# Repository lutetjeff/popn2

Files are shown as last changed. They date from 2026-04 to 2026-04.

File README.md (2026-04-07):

# popn2 (lutet)

version 2 of my personal pop'n music controller! we don't talk about version 1.

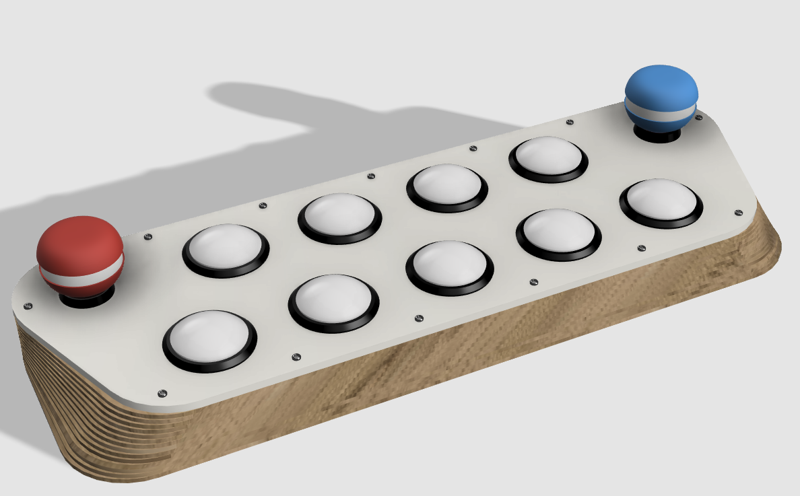
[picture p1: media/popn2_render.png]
Render of the Controller

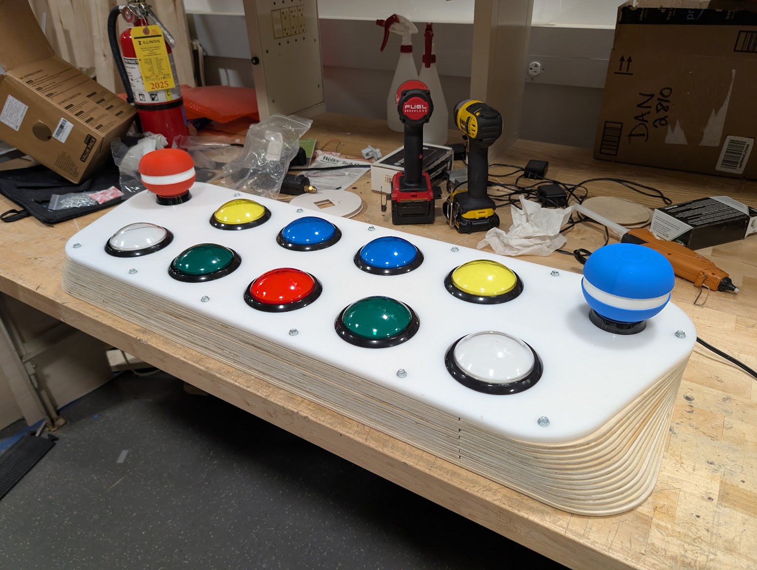
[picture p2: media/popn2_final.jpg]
Final Product

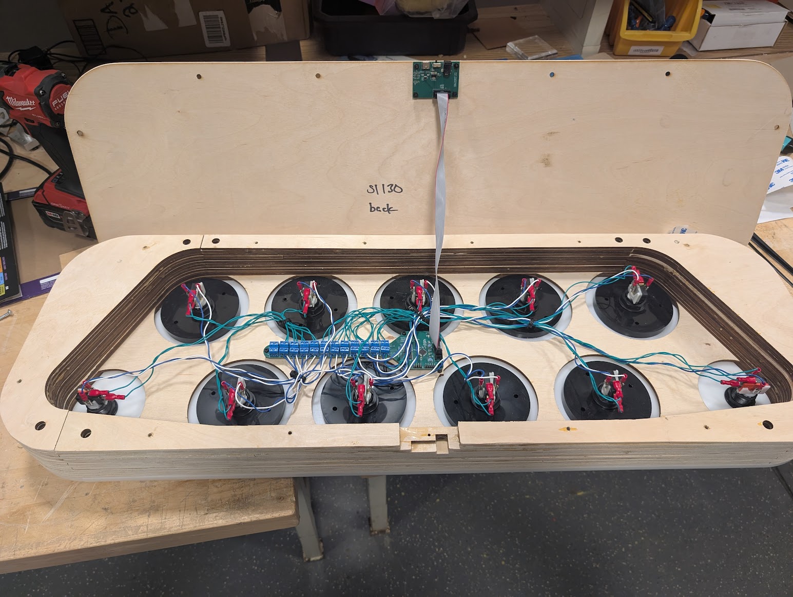
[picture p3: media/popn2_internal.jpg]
Internal Shot


here is me clearing my first 44 on this controller: [video link](https://github.com/user-attachments/assets/4b452afc-de7f-416d-95ad-3e25626bb59a)

## Repository Hierarchy

- **`daughterboard/`**: KiCAD PCB files for the USB and power daughterboard.
- **`firmware/`**: Source code for the mainboard's firmware.
- **`mainboard/`**: KiCAD PCB files for the STM32F072 mainboard.
- **`media/`**: Images, renders, and video showcases of the controller.
- **`production/`**: Vector files for laser-cutting the physical enclosure layers.
- **`popn2.f3z`**: Fusion 360 source file for the mechanical design.

## Mechanical Design

The physical enclosure of the controller is built using a stacked layer design. The stackup consists of:
- **13 layers of birch plywood** (Layers 1 through 13). The nominal thickness is 1/4", but the actual real-world thickness is about **5.2mm** per layer.
- **1 layer of acetal/POM** measuring **3/8" (9.5mm)** thick for the top layer.

### Buttons & Hardware
- **Gameplay Buttons:** We use 100mm Samducksa buttons from ISTMALL for the 9 main gameplay buttons. We highly recommend getting the aftermarket 100g Samducksa springs from ISTMALL rather than using the stock springs.
- **Side Buttons (Pop-kuns):** The side buttons are these 60mm OEM round buttons: [Amazon Link](https://www.amazon.com/dp/B09CYMDZCR)

## Mainboard

The mainboard is powered by an **STM32F072** microcontroller, and also functions as a generic 12-input 12-output arcade game controller. It uses individual pins for each button and darlington arrays to drive 12V LEDs.

## Daughterboard

The daughterboard handles the external inputs for the controller. The KiCAD PCB files define a board that takes **12V and USB in** and passes them along to the mainboard via a **10-pin (2x5) ribbon cable**.

## Firmware

The firmware for the STM32F072 on the mainboard is included in this repository.
For more details, please see the [firmware README](firmware/README.md).

## Production

The `production/` folder contains the production files for laser cutting each individual layer. 
The naming convention for these files is `sl[layer][part]`, where `[part]` is at most one digit.
There are also combined production files in `production/combined/` - beware that one of the pieces is missing and I don't remember which one. 

## Special Thanks

- **Illini Rhythm Syndicate** ([link](https://uiucirs.com))
- **ECE OpenLab at UIUC** ([link](https://openlab.ece.illinois.edu/))

## As Seen At

- Rumble In The Prairie 15 (RIP 15) - [link](https://www.start.gg/tournament/rumble-in-the-prairie-15/details)
- IRSCTF 2026 - [link](https://ctf.uiucirs.com/)
- This controller is so awesome [they made a whole song about it](https://www.youtube.com/watch?v=c7E-tgmFuzw)

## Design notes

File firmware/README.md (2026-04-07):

# popn2_firmware

STM32F072CBT6 firmware for a 12-input, 12-output rhythm game controller.

## Hardware

- **MCU**: STM32F072CBT6 (ARM Cortex-M0, 48MHz)
- **Inputs**: 12 buttons (B0-B11), active-low with pull-ups
- **Outputs**: 12 LEDs (L0-L11)
- **USB**: 1kHz HID + CDC

## Features

- **NKRO Keyboard HID**: All 12 buttons report simultaneously as HID keyboard keys
- **CDC Serial Config**: Virtual COM port for runtime configuration
- **Flash Persistence**: All settings saved to internal flash
- **DFU Bootloader**: Jump to ST's built-in ROM bootloader for firmware updates

## Building & Flashing

Requires [STM32-for-VSCode](https://marketplace.visualstudio.com/items?item=bmd.stm32-for-vscode) extension.

```bash
# Build
Ctrl+Shift+B > Build STM

# Flash
Ctrl+Shift+B > Flash STM
```

## Configuration Commands (CDC)

Connect to the Virtual COM port at 115200 baud.

| Command | Description |
|---|---|
| `e 0/1` | Disable/Enable global LEDs |
| `t <ms>` | Set global debounce time (ms) |
| `k <btn> <hex>` | Set keycode for button (e.g. `k 0 0x04`) |
| `m <btn> <mode>` | Set LED mode: 0=Direct, 1=COM Controlled |
| `d <btn> 0/1` | Set COM state for button LED control |
| `r <btn>` | Read current button state |
| `S` | Save current config to flash |
| `R` | Reset to defaults and save |
| `Z` | Reboot into DFU bootloader |

## Python Configurator

Run `configurator.py` for a graphical interface to configure all settings and monitor button states in real-time.

```bash
python configurator.py
```

## Pin Mapping

| Button | Pin | LED | Pin |
|---|-----|-----|-----|
| B0 | PA0 | L0 | PB12 |
| B1 | PA1 | L1 | PB13 |
| B2 | PA2 | L2 | PB14 |
| B3 | PA3 | L3 | PB15 |
| B4 | PA4 | L4 | PA8 |
| B5 | PA5 | L5 | PA9 |
| B6 | PA6 | L6 | PA10 |
| B7 | PA7 | L7 | PA15 |
| B8 | PB0 | L8 | PB3 |
| B9 | PB1 | L9 | PB4 |
| B10 | PB2 | L10 | PB5 |
| B11 | PB10 | L11 | PB6 |

## Default Keymap

B0-B9 map to HID keys `0`-`9`, B10 to `-`, B11 to `=`.

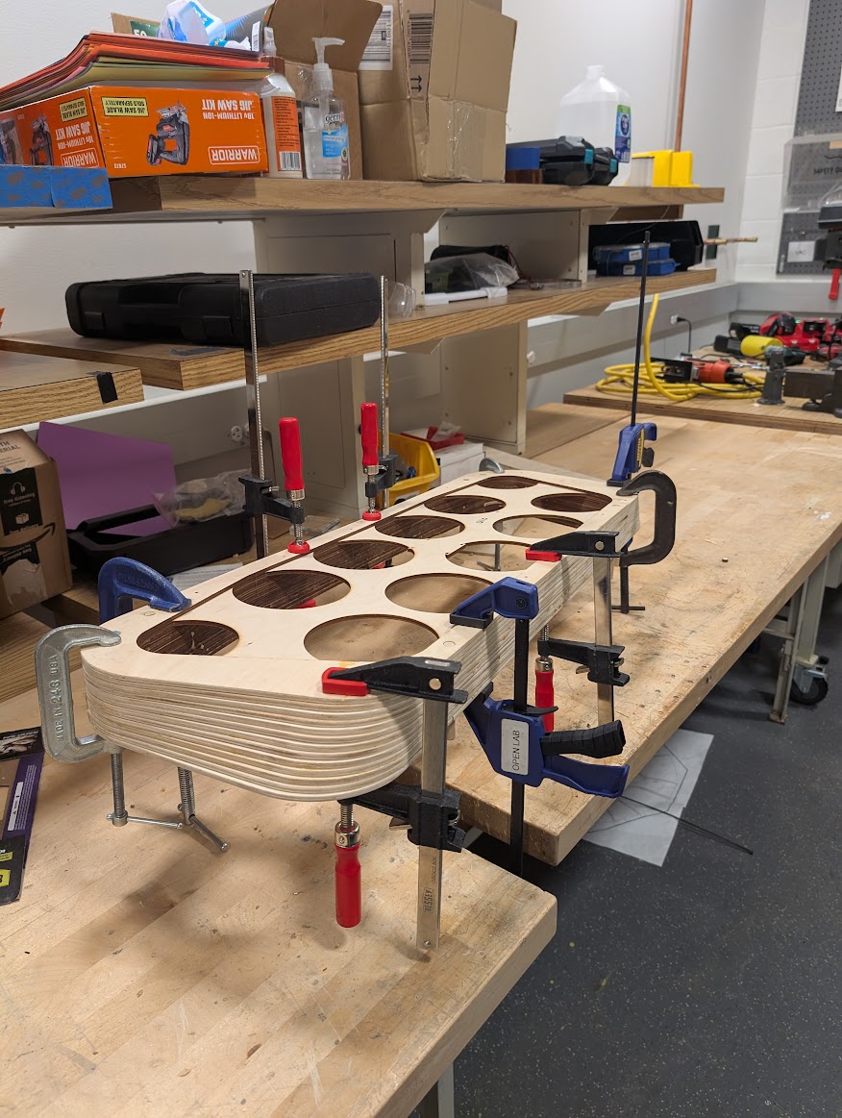
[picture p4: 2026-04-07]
media/popn2_wip.jpg

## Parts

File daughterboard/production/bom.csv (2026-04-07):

Designator | Footprint | Quantity | Value | LCSC Part #
C1 | 0805 | 1 | 1uF
C2 | 0805 | 1 | 2.2uF
D+ | TestPoint_Pad_1.5x1.5mm | 1 | D+
D- | TestPoint_Pad_1.5x1.5mm | 1 | D-
J1 | BarrelJack_Horizontal | 1 | Barrel_Jack_MountingPin
J2 | USB_C_Receptacle_HRO_TYPE-C-31-M-12 | 1 | USB_C_Receptacle_USB2.0_16P
J3 | PinHeader_2x03_P2.54mm_Vertical | 1 | PWR
J4 | PinHeader_1x02_P2.54mm_Vertical | 1 | DATA
J5 | IDC-Header_2x05_P2.54mm_Vertical | 1 | ribbon
R1, R2 | 0805 | 2 | 5.1k
SW1 | SW_Slide_SPDT_Angled_CK_OS102011MA1Q | 1 | SW_SPDT
U1 | SOT-223-3_TabPin2 | 1 | TLV76133DCY
U2 | SOT-23-6 | 1 | USBLC6-2SC6

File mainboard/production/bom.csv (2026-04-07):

Designator | Footprint | Quantity | Value | LCSC Part #
C1, C2, C3, C4 | 0805 | 4 | 0.1uF
C5 | 0805 | 1 | 1uF
D1, D2, D3, D4, D5 | 0805 | 5 | LED
J1 | IDC-Header_2x05_P2.54mm_Vertical | 1 | ribbon
J10, J11, J12, J13, J14, J15, J16, J17, J18, J19, J20, J21, J22, J23, J24, J25, J26, J3, J4, J5, J6, J7, J8, J9 | TerminalBlock_MaiXu_MX126-5.0-02P_1x02_P5.00mm | 24 | Conn_01x02
J2 | PinSocket_1x05_P2.54mm_Vertical | 1 | Conn_01x05
J27 | PinHeader_1x04_P2.54mm_Vertical | 1 | Conn_01x04
J28 | PinHeader_1x03_P2.54mm_Vertical | 1 | Conn_01x03
R1, R19, R2 | 0805 | 3 | 10k
R10, R11, R12, R13, R14, R15, R16, R5, R6, R7, R8, R9 | 0805 | 12 | 0
R17, R3, R4 | 0805 | 3 | 2.2k
R18 | 0805 | 1 | 4.7k
SW1, SW2 | SW_SPST_PTS810 | 2 | SW_Push
U1 | LQFP-48_7x7mm_P0.5mm | 1 | STM32F072C8Tx
U2, U3 | SOIC-16_3.9x9.9mm_P1.27mm | 2 | ULN2003A

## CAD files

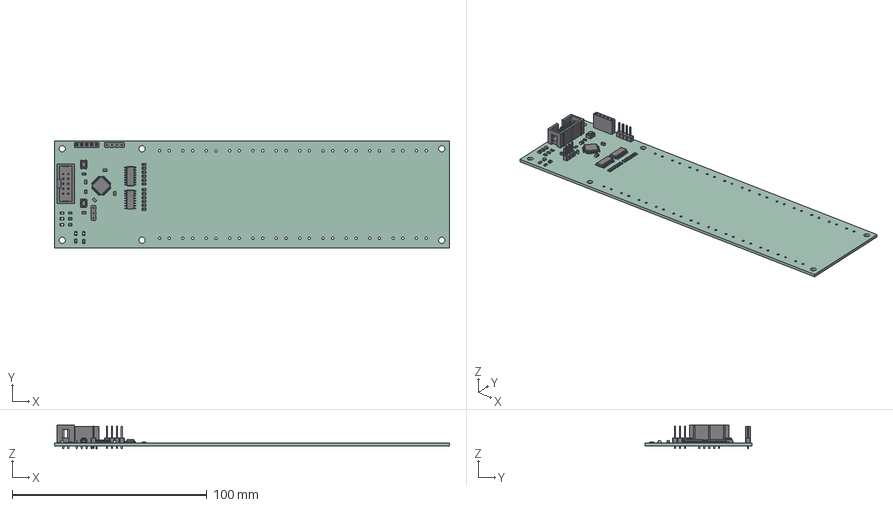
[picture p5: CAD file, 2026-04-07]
mainboard/mainboard_noss.step
203.0 x 55.0 x 12.2 mm
R_0805_2012Metric x 19
PinHeader_1x03_P2.54mm_Vertical
SOIC-16_3.9x9.9mm_P1.27mm x 2
C_0805_2012Metric x 5
SW_SPST_PTS810 x 2
LED_0805_2012Metric x 5
PinSocket_1x05_P2.54mm_Vertical
PinHeader_1x04_P2.54mm_Vertical
IDC-Header_2x05_P2.54mm_Vertical
LQFP-48_7x7mm_P0.5mm
mainboard_PCB

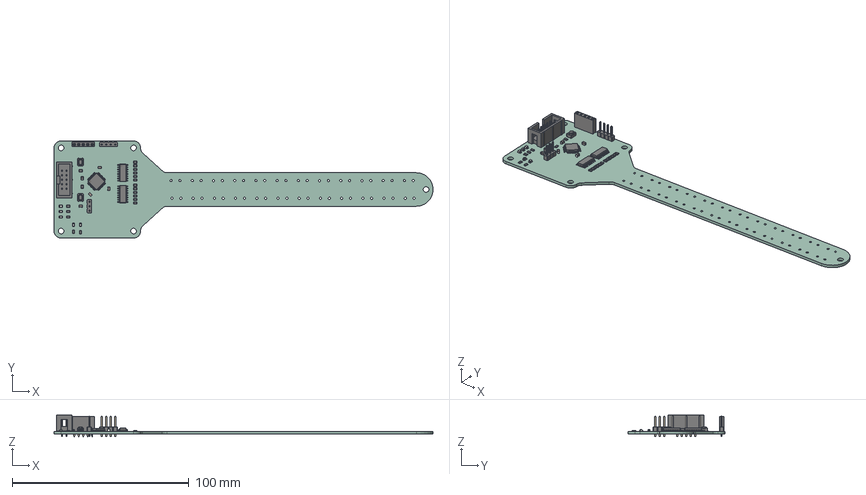
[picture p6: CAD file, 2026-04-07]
mainboard/mainboard_2.step
214.4 x 55.0 x 12.2 mm
R_0805_2012Metric x 19
PinHeader_1x03_P2.54mm_Vertical
SOIC-16_3.9x9.9mm_P1.27mm x 2
C_0805_2012Metric x 5
SW_SPST_PTS810 x 2
LED_0805_2012Metric x 5
PinSocket_1x05_P2.54mm_Vertical
PinHeader_1x04_P2.54mm_Vertical
IDC-Header_2x05_P2.54mm_Vertical
LQFP-48_7x7mm_P0.5mm
mainboard_PCB

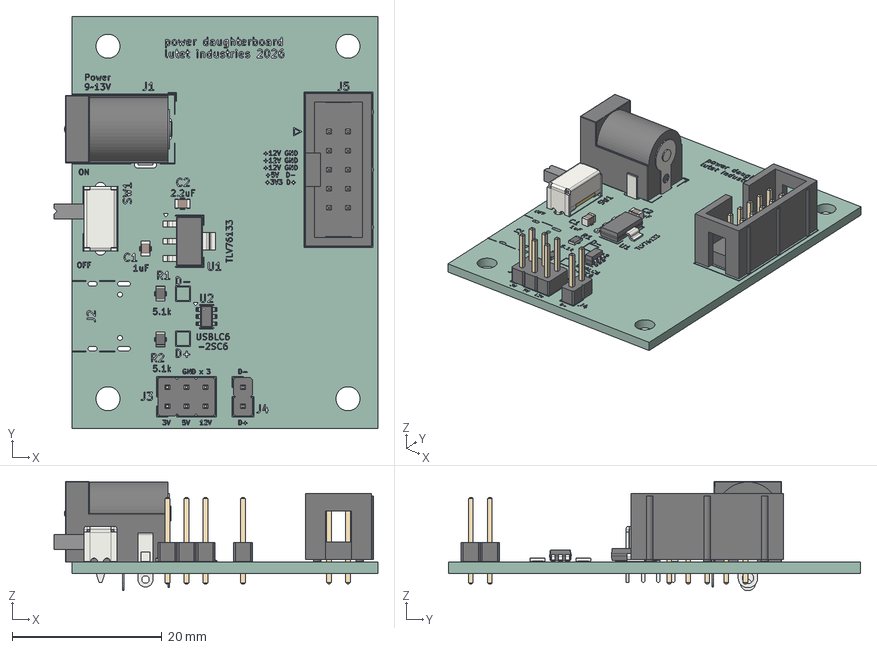
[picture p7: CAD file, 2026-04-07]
daughterboard/daughterboard.step
43.2 x 55.0 x 14.6 mm
SOT-223
C_0805_2012Metric x 2
SOT-23-6
IDC-Header_2x05_P2.54mm_Vertical
BarrelJack_Horizontal
R_0805_2012Metric x 2
PinHeader_2x03_P2.54mm_Vertical
PinHeader_1x02_P2.54mm_Vertical
SW_Slide_SPDT_Angled_CK_OS102011MA1Q
daughterboard_silkscreen x 2
daughterboard_PCB

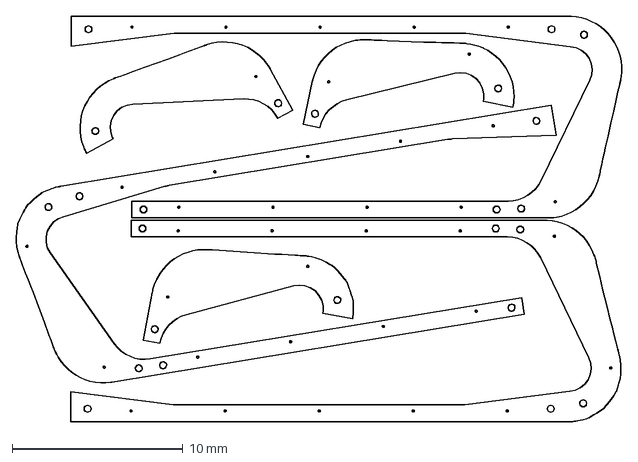
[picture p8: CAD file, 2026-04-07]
production/combined/sl30_41_50_60_71_80.dxf
35.5 x 23.8 mm

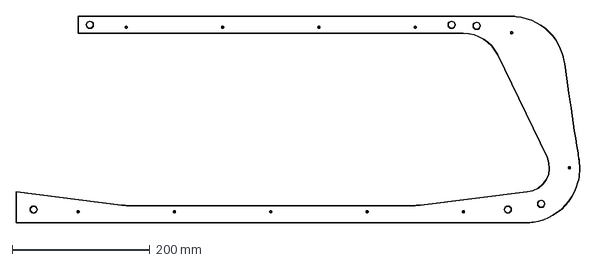
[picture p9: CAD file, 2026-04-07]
production/sl70.dxf
819.2 x 300.0 mm

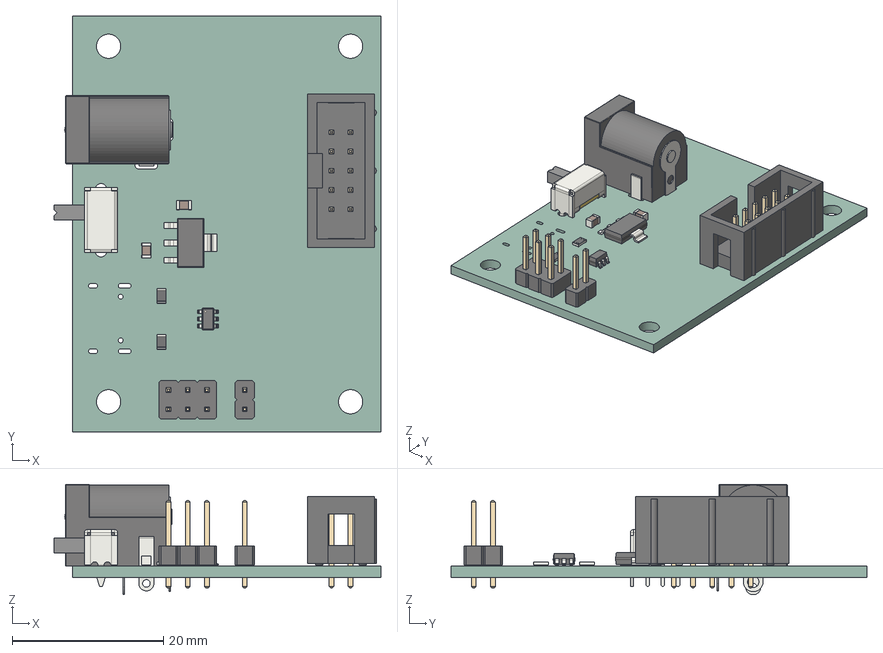
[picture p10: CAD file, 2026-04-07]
daughterboard/daughterboard_noss.step
43.2 x 55.0 x 14.6 mm
SOT-223
C_0805_2012Metric x 2
SOT-23-6
IDC-Header_2x05_P2.54mm_Vertical
BarrelJack_Horizontal
R_0805_2012Metric x 2
PinHeader_2x03_P2.54mm_Vertical
PinHeader_1x02_P2.54mm_Vertical
SW_Slide_SPDT_Angled_CK_OS102011MA1Q
daughterboard_PCB

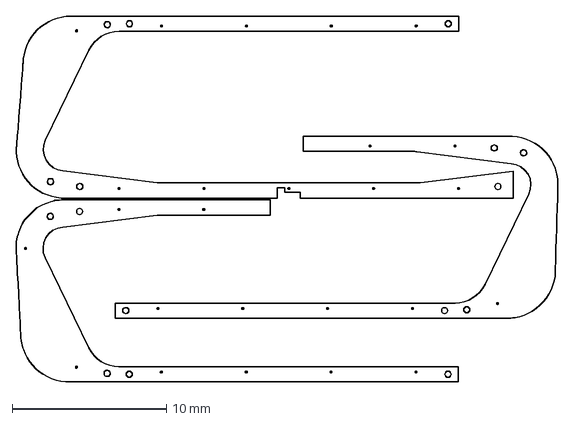
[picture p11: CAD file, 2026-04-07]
production/combined/sl_101_110_122.dxf
35.2 x 23.7 mm

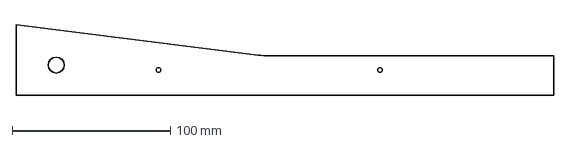
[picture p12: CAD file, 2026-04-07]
production/sl112.dxf
340.0 x 44.8 mm

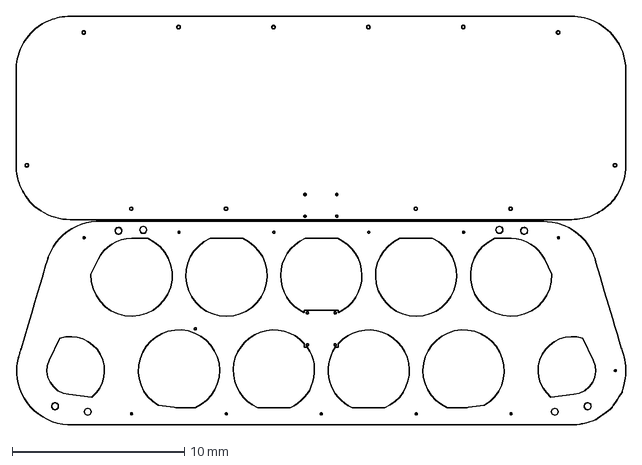
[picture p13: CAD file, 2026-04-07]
production/combined/sl10_130.dxf
35.4 x 23.7 mm

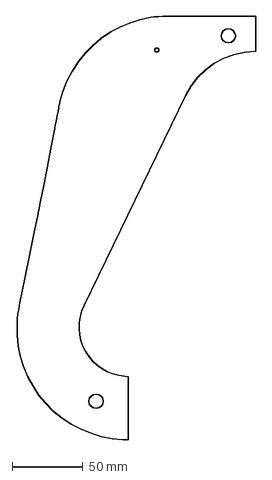
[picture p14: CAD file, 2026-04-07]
production/sl51.dxf
169.4 x 300.0 mm

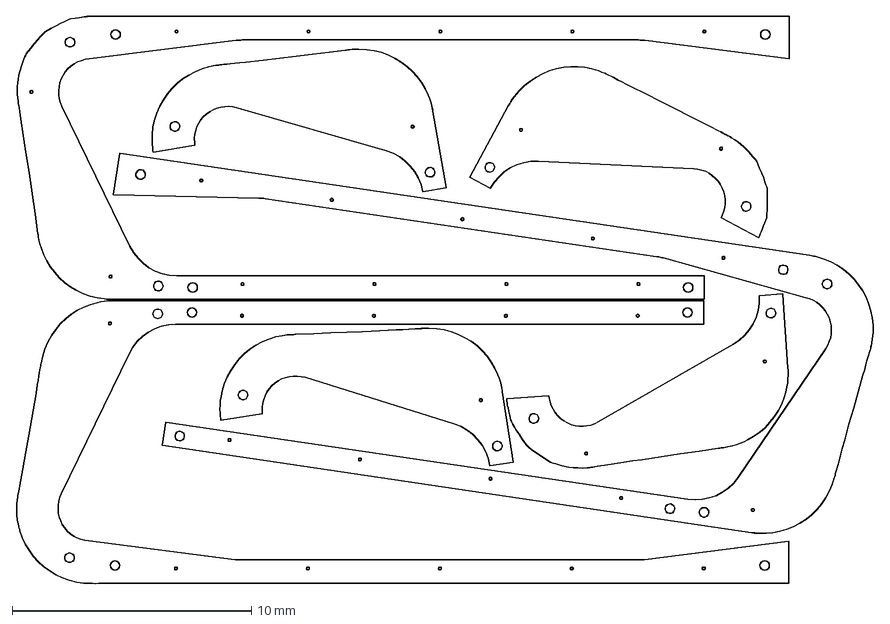
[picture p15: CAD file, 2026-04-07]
production/combined/sl61_70_81_90_91_100_111_120.dxf
35.8 x 23.7 mm

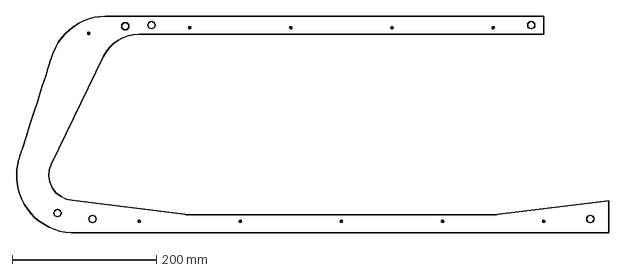
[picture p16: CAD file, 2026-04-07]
production/sl01.dxf
820.0 x 300.0 mm

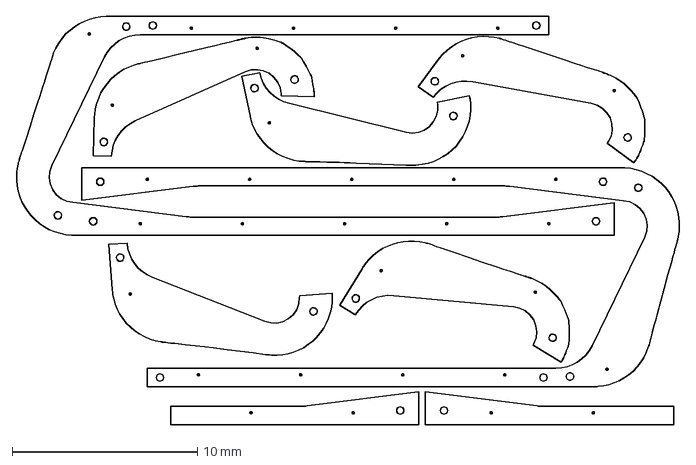
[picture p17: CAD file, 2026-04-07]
production/combined/sl00_01_20_21_31_40_51_112_121.dxf
35.8 x 22.0 mm

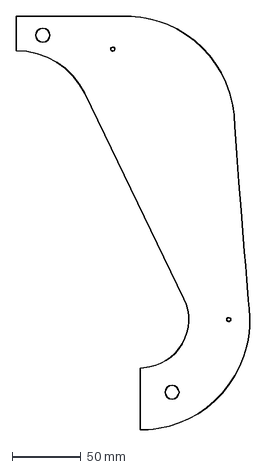
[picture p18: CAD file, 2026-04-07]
production/sl100.dxf
169.3 x 300.0 mm

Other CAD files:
production/sl120.dxf
production/sl80.dxf
production/top.dxf
production/sl122.dxf
production/foam.dxf
production/sl00.dxf
production/sl10.dxf
production/sl101.dxf
production/sl110.dxf
production/sl111.dxf
production/sl121.dxf
production/sl130.dxf
production/sl20.dxf
production/sl21.dxf
production/sl30.dxf
production/sl31.dxf
production/sl40.dxf
production/sl41.dxf
production/sl50.dxf
production/sl60.dxf
production/sl61.dxf
production/sl71.dxf
production/sl81.dxf
production/sl90.dxf
production/sl91.dxf

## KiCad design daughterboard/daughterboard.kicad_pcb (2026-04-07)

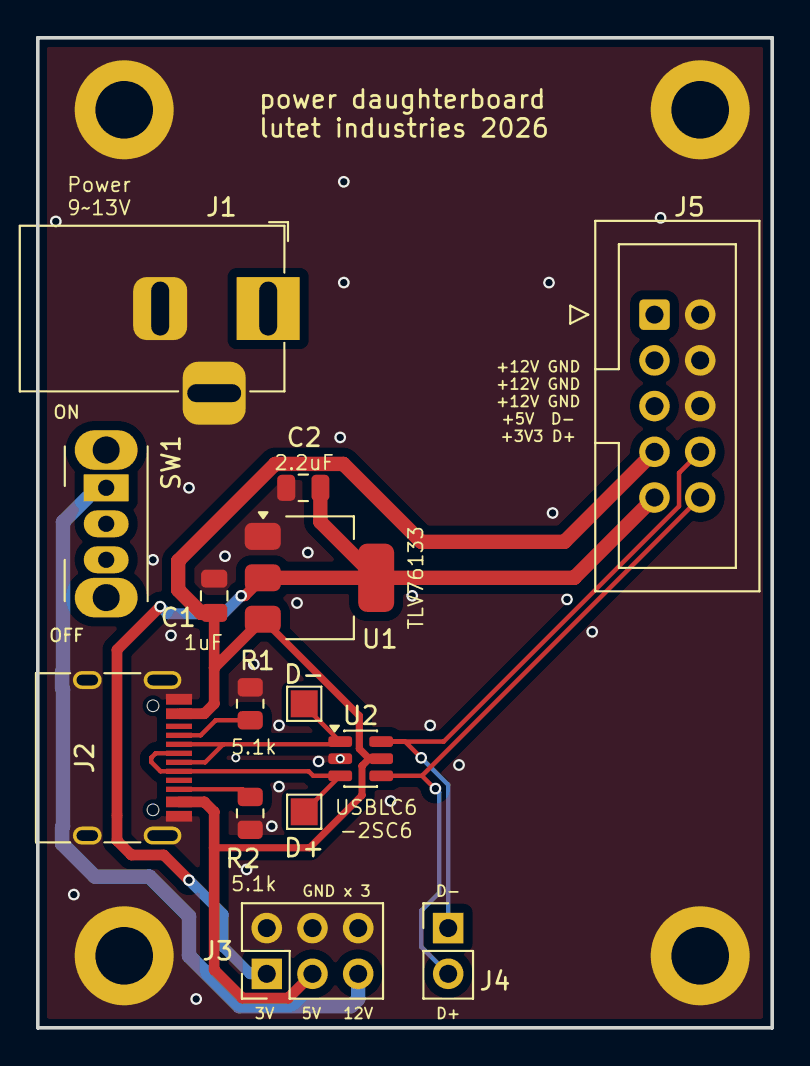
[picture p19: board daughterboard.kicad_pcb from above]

Board: 2 copper layers, 40.8 x 55.0 mm, 18 parts (0 on the bottom side), 11 nets.

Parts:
C1: 1uF; C_0805_2012Metric
C2: 2.2uF; C_0805_2012Metric
D+: D+; TestPoint_Pad_1.5x1.5mm
D-: D-; TestPoint_Pad_1.5x1.5mm
H1, H2, H3, H4: MountingHole_Pad; MountingHole_3.2mm_M3_ISO14580_Pad
J1: Barrel_Jack_MountingPin; BarrelJack_Horizontal
J2: USB_C_Receptacle_USB2.0_16P; USB_C_Receptacle_HRO_TYPE-C-31-M-12
J3: PWR; PinHeader_2x03_P2.54mm_Vertical
J4: DATA; PinHeader_1x02_P2.54mm_Vertical
J5: ribbon; IDC-Header_2x05_P2.54mm_Vertical
R1, R2: 5.1k; R_0805_2012Metric
SW1: SW_SPDT; SW_Slide_SPDT_Angled_CK_OS102011MA1Q
U1: TLV76133DCY; SOT-223-3_TabPin2
U2: USBLC6-2SC6; SOT-23-6

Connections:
+3V3: C2.1, J3.1, J5.9, U1.2 (VO)
+5V: C1.1, J2.A4 (VBUS), J2.A9 (VBUS), J2.B4 (VBUS), J2.B9 (VBUS), J3.3, J5.7, U1.3 (VI), U2.5 (VBUS)
+12V: J3.5, J5.1, J5.3, J5.5, SW1.1 (A)
D+: J4.2, J5.10, U2.4 (I/O2)
D-: J4.1, J5.8, U2.6 (I/O1)
GND: C1.2, C2.2, H1.1, H2.1, H3.1, H4.1, J1.2, J1.3 (MountPin), J2.A1 (GND), J2.A12 (GND), J2.B1 (GND), J2.B12 (GND), J2.S1 (SHIELD), J3.2, J3.4, J3.6, J5.2, J5.4, J5.6, R1.2, R2.2, U1.1 (GND), U2.2 (GND)
unnamed: J2.A5 (CC1), R1.1
unnamed: J2.B5 (CC2), R2.1
unnamed: D+.1, J2.A6 (D+), J2.B6 (D+), U2.3 (I/O2)
unnamed: D-.1, J2.A7 (D-), J2.B7 (D-), U2.1 (I/O1)
unnamed: J1.1, SW1.2 (B)

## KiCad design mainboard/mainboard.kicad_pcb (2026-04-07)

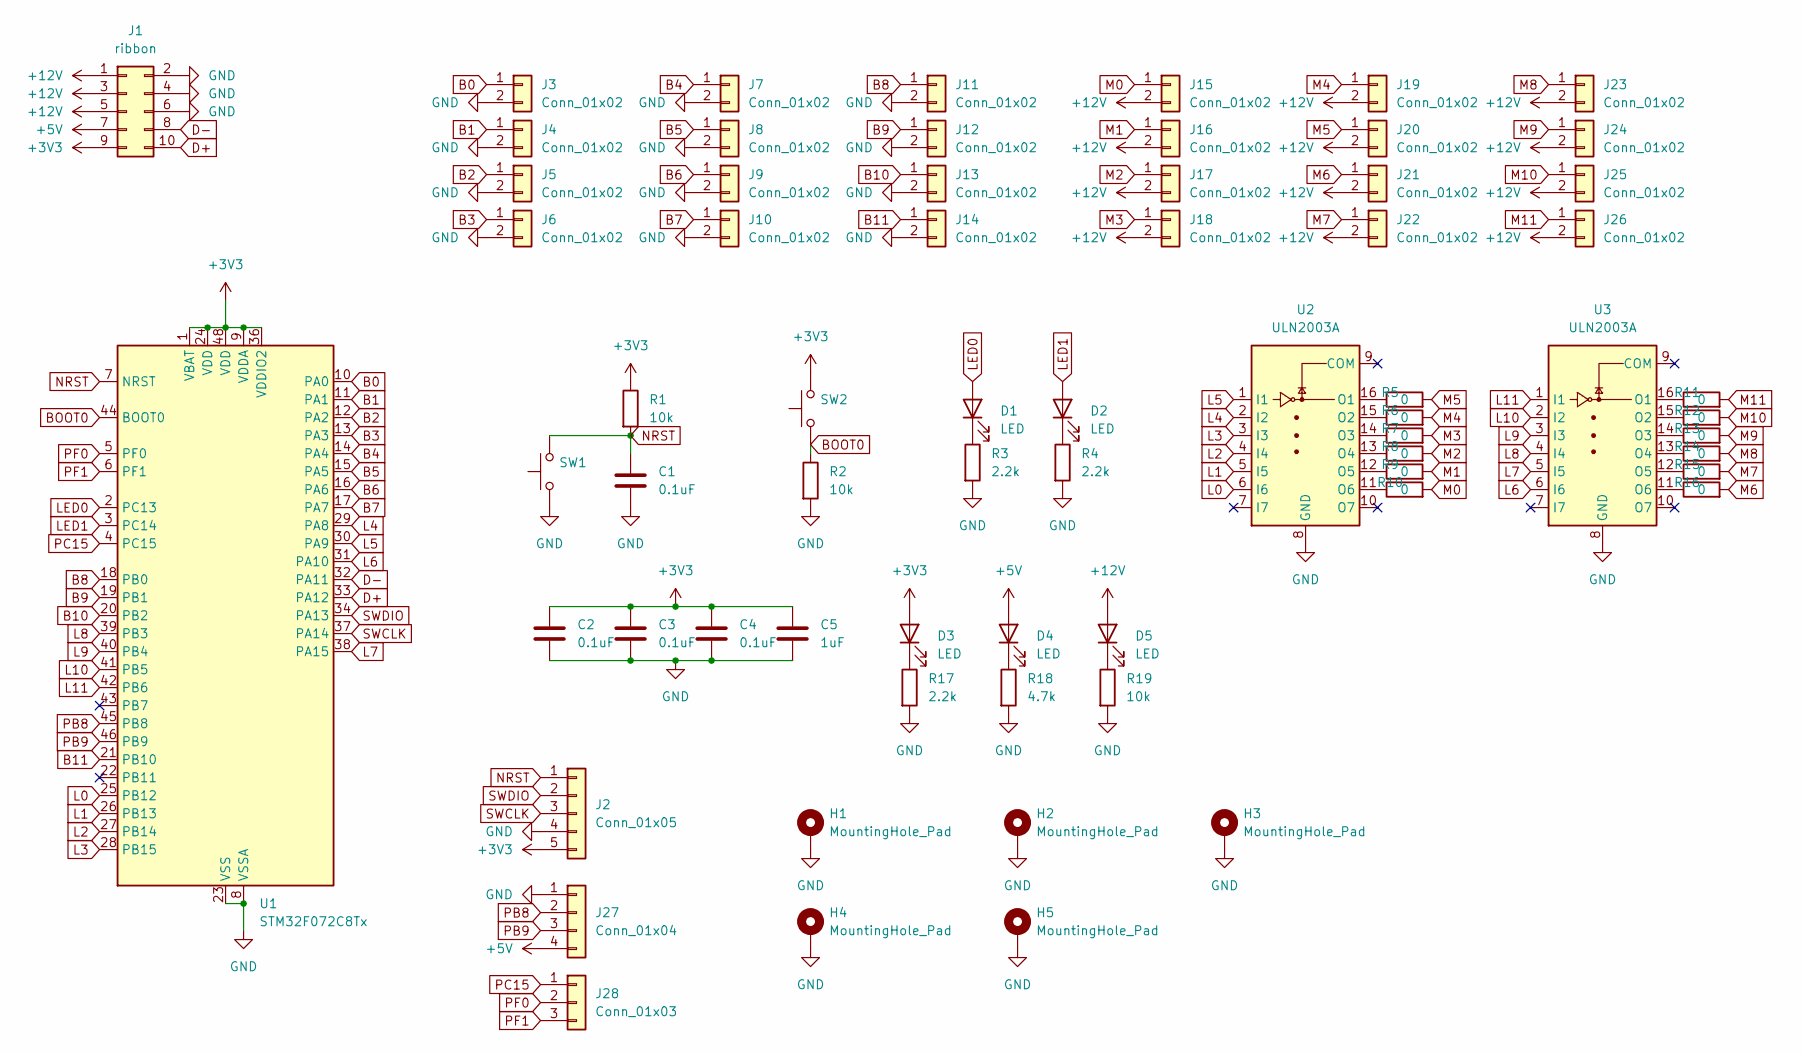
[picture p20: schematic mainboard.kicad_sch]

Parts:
C1, C2, C3, C4: 0.1uF; C_0805_2012Metric
C5: 1uF; C_0805_2012Metric
D1, D2, D3, D4, D5: LED; LED_0805_2012Metric
H1, H2, H3, H4, H5: MountingHole_Pad; MountingHole_3.2mm_M3_ISO14580_Pad
J1: ribbon; IDC-Header_2x05_P2.54mm_Vertical
J2: Conn_01x05; PinSocket_1x05_P2.54mm_Vertical
J3, J4, J5, J6, J7, J8, J9, J10, J11, J12, J13, J14, J15, J16, J17, J18, J19, J20, J21, J22, J23, J24, J25, J26: Conn_01x02; TerminalBlock_MaiXu_MX126-5.0-02P_1x02_P5.00mm
J27: Conn_01x04; PinHeader_1x04_P2.54mm_Vertical
J28: Conn_01x03; PinHeader_1x03_P2.54mm_Vertical
R1, R2, R19: 10k; R_0805_2012Metric
R3, R4, R17: 2.2k; R_0805_2012Metric
R5, R6, R7, R8, R9, R10, R11, R12, R13, R14, R15, R16: 0; R_0805_2012Metric
R18: 4.7k; R_0805_2012Metric
SW1, SW2: SW_Push; SW_SPST_PTS810
U1: STM32F072C8Tx; LQFP-48_7x7mm_P0.5mm
U2, U3: ULN2003A; SOIC-16_3.9x9.9mm_P1.27mm

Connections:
+3V3: C2.1, C3.1, C4.1, C5.1, D3.2 (A), J1.9, J2.5, R1.1, SW2.2, U1.1 (VBAT), U1.9 (VDDA), U1.24 (VDD), U1.36 (VDDIO2), U1.48 (VDD)
+5V: D4.2 (A), J1.7, J27.4
+12V: D5.2 (A), J1.1, J1.3, J1.5, J15.2, J16.2, J17.2, J18.2, J19.2, J20.2, J21.2, J22.2, J23.2, J24.2, J25.2, J26.2
B0: J3.1, U1.10 (PA0)
B1: J4.1, U1.11 (PA1)
B2: J5.1, U1.12 (PA2)
B3: J6.1, U1.13 (PA3)
B4: J7.1, U1.14 (PA4)
B5: J8.1, U1.15 (PA5)
B6: J9.1, U1.16 (PA6)
B7: J10.1, U1.17 (PA7)
B8: J11.1, U1.18 (PB0)
B9: J12.1, U1.19 (PB1)
B10: J13.1, U1.20 (PB2)
B11: J14.1, U1.21 (PB10)
BOOT0: R2.1, SW2.1, U1.44 (BOOT0)
D+: J1.10, U1.33 (PA12)
D-: J1.8, U1.32 (PA11)
GND: C1.2, C2.2, C3.2, C4.2, C5.2, H1.1, H2.1, H3.1, H4.1, H5.1, J1.2, J1.4, J1.6, J2.4, J3.2, J4.2, J5.2, J6.2, J7.2, J8.2, J9.2, J10.2, J11.2, J12.2, J13.2, J14.2, J27.1, R2.2, R3.2, R4.2, R17.2, R18.2, R19.2, SW1.1, U1.8 (VSSA), U1.23 (VSS), U1.35 (VSS), U1.47 (VSS), U2.8 (GND), U3.8 (GND)
L0: U1.25 (PB12), U2.6 (I6)
L1: U1.26 (PB13), U2.5 (I5)
L2: U1.27 (PB14), U2.4 (I4)
L3: U1.28 (PB15), U2.3 (I3)
L4: U1.29 (PA8), U2.2 (I2)
L5: U1.30 (PA9), U2.1 (I1)
L6: U1.31 (PA10), U3.6 (I6)
L7: U1.38 (PA15), U3.5 (I5)
L8: U1.39 (PB3), U3.4 (I4)
L9: U1.40 (PB4), U3.3 (I3)
L10: U1.41 (PB5), U3.2 (I2)
L11: U1.42 (PB6), U3.1 (I1)
LED0: D1.2 (A), U1.2 (PC13)
LED1: D2.2 (A), U1.3 (PC14)
M0: J15.1, R10.2
M1: J16.1, R9.2
M2: J17.1, R8.2
M3: J18.1, R7.2
M4: J19.1, R6.2
M5: J20.1, R5.2
M6: J21.1, R16.2
M7: J22.1, R15.2
M8: J23.1, R14.2
M9: J24.1, R13.2
M10: J25.1, R12.2
M11: J26.1, R11.2
NRST: C1.1, J2.1, R1.2, SW1.2, U1.7 (NRST)
unnamed: D1.1 (K), R3.1
unnamed: D2.1 (K), R4.1
unnamed: D3.1 (K), R17.1
unnamed: D4.1 (K), R18.1
unnamed: D5.1 (K), R19.1
unnamed: R5.1, U2.16 (O1)
unnamed: R6.1, U2.15 (O2)
unnamed: R7.1, U2.14 (O3)
unnamed: R8.1, U2.13 (O4)
unnamed: R9.1, U2.12 (O5)
unnamed: R10.1, U2.11 (O6)
unnamed: R11.1, U3.16 (O1)
unnamed: R12.1, U3.15 (O2)
unnamed: R13.1, U3.14 (O3)
unnamed: R14.1, U3.13 (O4)
unnamed: R15.1, U3.12 (O5)
unnamed: R16.1, U3.11 (O6)
PB8: J27.2, U1.45 (PB8)
PB9: J27.3, U1.46 (PB9)
PC15: J28.1, U1.4 (PC15)
PF0: J28.2, U1.5 (PF0)
PF1: J28.3, U1.6 (PF1)
SWCLK: J2.3, U1.37 (PA14)
SWDIO: J2.2, U1.34 (PA13)

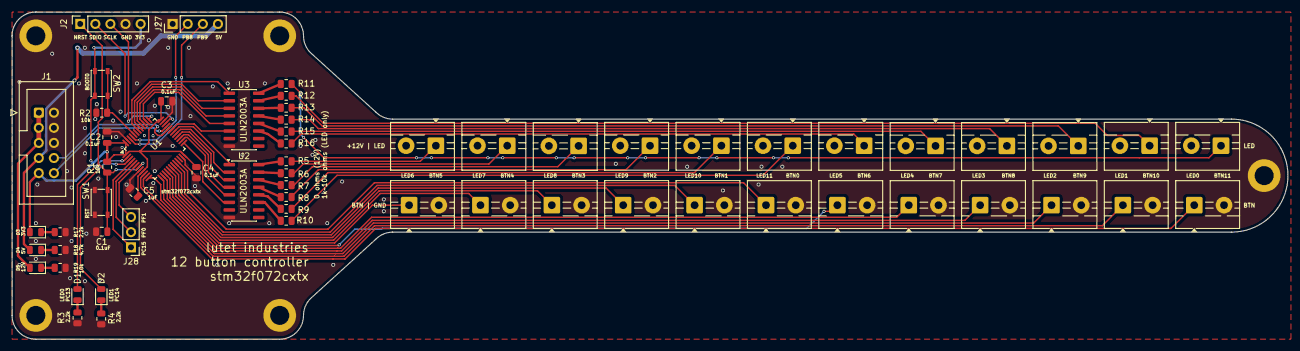
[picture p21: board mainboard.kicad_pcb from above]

Board: 2 copper layers, 214.5 x 55.0 mm, 67 parts (0 on the bottom side), 70 nets.

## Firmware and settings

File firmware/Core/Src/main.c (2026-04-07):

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
/* Includes ------------------------------------------------------------------*/
#include "main.h"

/* USER CODE BEGIN Includes */
#include "tusb.h"
#include "tasks.h"
/* USER CODE END Includes */

TIM_HandleTypeDef htim2;

PCD_HandleTypeDef hpcd_USB_FS;

void SystemClock_Config(void);
static void MX_GPIO_Init(void);
static void MX_USB_PCD_Init(void);
static void MX_TIM2_Init(void);
/* USER CODE BEGIN 0 */
void check_dfu_magic(void) {
    // Check if the magic word survived the reset
    if (*((volatile uint32_t *)DFU_MAGIC_ADDR) == DFU_MAGIC_WORD) {
        
        // Clear it so we don't get stuck in a bootloop
        *((volatile uint32_t *)DFU_MAGIC_ADDR) = 0;

        // Enable the SYSCFG clock (using direct registers to avoid HAL)
        RCC->APB2ENR |= RCC_APB2ENR_SYSCFGEN;

        // Remap System Memory to 0x00000000 (Required for F072)
        SYSCFG->CFGR1 = (SYSCFG->CFGR1 & ~SYSCFG_CFGR1_MEM_MODE) | 0x01; 

        // Load the bootloader's stack pointer and execution address
        uint32_t jump_addr = *(__IO uint32_t *)(BOOTLOADER_ADDR + 4);
        void (*SysMemBootJump)(void) = (void (*)(void))jump_addr;

        // Set the main stack pointer
        __set_MSP(*(__IO uint32_t *)BOOTLOADER_ADDR);

        // Jump!
        SysMemBootJump();
    }
}
/* USER CODE END 0 */

/**
  * @brief  The application entry point.
  * @retval int
  */
int main(void)
{

  /* USER CODE BEGIN 1 */
  check_dfu_magic();
  /* USER CODE END 1 */

  /* MCU Configuration--------------------------------------------------------*/

  /* Reset of all peripherals, Initializes the Flash interface and the Systick. */
  HAL_Init();

  /* Configure the system clock */
  SystemClock_Config();

  /* Initialize all configured peripherals */
  MX_GPIO_Init();
  MX_USB_PCD_Init();
  MX_TIM2_Init();
  /* USER CODE BEGIN 2 */
  tusb_rhport_init_t dev_init = {
    .role  = TUSB_ROLE_DEVICE,
    .speed = TUSB_SPEED_FULL
  };
  tusb_init(0, &dev_init);
  tasks_init();

  /* USER CODE END 2 */

  /* Infinite loop */
  /* USER CODE BEGIN WHILE */
  while (1)
  {
    /* USER CODE END WHILE */

    /* USER CODE BEGIN 3 */
    tud_task();
    gpio_task();
    cdc_task();
    hid_task();
  }
  /* USER CODE END 3 */
}

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


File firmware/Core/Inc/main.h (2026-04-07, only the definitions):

#define LED0_Pin GPIO_PIN_13
#define LED0_GPIO_Port GPIOC
#define LED1_Pin GPIO_PIN_14
#define LED1_GPIO_Port GPIOC
#define B0_Pin GPIO_PIN_0
#define B0_GPIO_Port GPIOA
#define B1_Pin GPIO_PIN_1
#define B1_GPIO_Port GPIOA
#define B2_Pin GPIO_PIN_2
#define B2_GPIO_Port GPIOA
#define B3_Pin GPIO_PIN_3
#define B3_GPIO_Port GPIOA
#define B4_Pin GPIO_PIN_4
#define B4_GPIO_Port GPIOA
#define B5_Pin GPIO_PIN_5
#define B5_GPIO_Port GPIOA
#define B6_Pin GPIO_PIN_6
#define B6_GPIO_Port GPIOA
#define B7_Pin GPIO_PIN_7
#define B7_GPIO_Port GPIOA
#define B8_Pin GPIO_PIN_0
#define B8_GPIO_Port GPIOB
#define B9_Pin GPIO_PIN_1
#define B9_GPIO_Port GPIOB
#define B10_Pin GPIO_PIN_2
#define B10_GPIO_Port GPIOB
#define B11_Pin GPIO_PIN_10
#define B11_GPIO_Port GPIOB
#define L0_Pin GPIO_PIN_12
#define L0_GPIO_Port GPIOB
#define L1_Pin GPIO_PIN_13
#define L1_GPIO_Port GPIOB
#define L2_Pin GPIO_PIN_14
#define L2_GPIO_Port GPIOB
#define L3_Pin GPIO_PIN_15
#define L3_GPIO_Port GPIOB
#define L4_Pin GPIO_PIN_8
#define L4_GPIO_Port GPIOA
#define L5_Pin GPIO_PIN_9
#define L5_GPIO_Port GPIOA
#define L6_Pin GPIO_PIN_10
#define L6_GPIO_Port GPIOA
#define L7_Pin GPIO_PIN_15
#define L7_GPIO_Port GPIOA
#define L8_Pin GPIO_PIN_3
#define L8_GPIO_Port GPIOB
#define L9_Pin GPIO_PIN_4
#define L9_GPIO_Port GPIOB
#define L10_Pin GPIO_PIN_5
#define L10_GPIO_Port GPIOB
#define L11_Pin GPIO_PIN_6
#define L11_GPIO_Port GPIOB

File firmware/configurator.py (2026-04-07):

import tkinter as tk
from tkinter import ttk, scrolledtext, messagebox
import serial
import serial.tools.list_ports
import re

# HID Hex Map
HID_KEYS = {
    "A": "0x04", "B": "0x05", "C": "0x06", "D": "0x07", "E": "0x08", "F": "0x09",
    "G": "0x0A", "H": "0x0B", "I": "0x0C", "J": "0x0D", "K": "0x0E", "L": "0x0F",
    "M": "0x10", "N": "0x11", "O": "0x12", "P": "0x13", "Q": "0x14", "R": "0x15",
    "S": "0x16", "T": "0x17", "U": "0x18", "V": "0x19", "W": "0x1A", "X": "0x1B",
    "Y": "0x1C", "Z": "0x1D",
    "1": "0x1E", "2": "0x1F", "3": "0x20", "4": "0x21", "5": "0x22", "6": "0x23",
    "7": "0x24", "8": "0x25", "9": "0x26", "0": "0x27",
    "Enter": "0x28", "Escape": "0x29", "Backspace": "0x2A", "Tab": "0x2B",
    "Spacebar": "0x2C", "Minus (-)": "0x2D", "Equals (=)": "0x2E"
}

BUTTONS = [f"B{i}" for i in range(12)]

class ControllerApp:
    def __init__(self, root):
        self.root = root
        self.root.title("STM32 Controller Configurator")
        self.root.geometry("680x600") # Made slightly taller for the new panel
        
        self.serial_conn = None
        self.rx_buffer = ""      # Used to assemble incoming serial characters into full lines
        self.is_polling = False  # State of the live read toggle
        
        self.setup_ui()
        self.refresh_ports()

    def setup_ui(self):
        # --- Top Frame: Connection ---
        conn_frame = tk.Frame(self.root, padx=10, pady=5)
        conn_frame.pack(fill=tk.X)

        tk.Label(conn_frame, text="COM Port:").pack(side=tk.LEFT)
        self.port_cb = ttk.Combobox(conn_frame, state="readonly", width=15)
        self.port_cb.pack(side=tk.LEFT, padx=5)
        
        tk.Button(conn_frame, text="Refresh", command=self.refresh_ports).pack(side=tk.LEFT)
        self.btn_connect = tk.Button(conn_frame, text="Connect", command=self.toggle_connection, width=12)
        self.btn_connect.pack(side=tk.LEFT, padx=10)

        # --- Main Content Split ---
        main_frame = tk.Frame(self.root, padx=10, pady=5)
        main_frame.pack(fill=tk.BOTH, expand=True)
        
        controls_frame = tk.Frame(main_frame)
        controls_frame.pack(side=tk.LEFT, fill=tk.Y, padx=(0, 10))

        terminal_frame = tk.Frame(main_frame)
        terminal_frame.pack(side=tk.RIGHT, fill=tk.BOTH, expand=True)

        # === CONTROLS SECTION ===

        # 1. Global Settings
        lf_global = tk.LabelFrame(controls_frame, text="Global Settings", padx=10, pady=10)
        lf_global.pack(fill=tk.X, pady=5)

        tk.Label(lf_global, text="Debounce (ms):").grid(row=0, column=0, sticky="w")
        self.debounce_var = tk.StringVar(value="10")
        tk.Entry(lf_global, textvariable=self.debounce_var, width=5).grid(row=0, column=1, padx=5)
        tk.Button(lf_global, text="Set", command=self.cmd_set_debounce).grid(row=0, column=2)

        tk.Label(lf_global, text="Global LEDs:").grid(row=1, column=0, sticky="w", pady=(5, 0))
        tk.Button(lf_global, text="Enable", command=lambda: self.send_cmd("e 1")).grid(row=1, column=1, pady=(5,0))
        tk.Button(lf_global, text="Disable", command=lambda: self.send_cmd("e 0")).grid(row=1, column=2, pady=(5,0))

        # 2. Button Configuration
        lf_btn = tk.LabelFrame(controls_frame, text="Button Configuration", padx=10, pady=10)
        lf_btn.pack(fill=tk.X, pady=5)

        tk.Label(lf_btn, text="Target Button:").grid(row=0, column=0, sticky="w")
        self.btn_sel_config = ttk.Combobox(lf_btn, values=BUTTONS, state="readonly", width=5)
        self.btn_sel_config.current(0)
        self.btn_sel_config.grid(row=0, column=1, columnspan=2, sticky="w", padx=5)

        tk.Label(lf_btn, text="Key Mapping:").grid(row=1, column=0, sticky="w", pady=(10, 0))
        self.key_cb = ttk.Combobox(lf_btn, values=list(HID_KEYS.keys()), state="readonly", width=10)
        self.key_cb.current(0)
        self.key_cb.grid(row=1, column=1, padx=5, pady=(10, 0))
        tk.Button(lf_btn, text="Apply", command=self.cmd_set_key).grid(row=1, column=2, pady=(10, 0))

        tk.Label(lf_btn, text="LED Mode:").grid(row=2, column=0, sticky="w", pady=(5, 0))
        self.mode_cb = ttk.Combobox(lf_btn, values=["0: Direct (Hardware)", "1: COM Controlled"], state="readonly", width=16)
        self.mode_cb.current(0)
        self.mode_cb.grid(row=2, column=1, columnspan=2, padx=5, pady=(5, 0), sticky="w")
        tk.Button(lf_btn, text="Apply", command=self.cmd_set_mode).grid(row=3, column=1, columnspan=2, pady=(5, 0), sticky="w", padx=5)


        # 3. LIVE HARDWARE DASHBOARD
        lf_live = tk.LabelFrame(controls_frame, text="Live Hardware State", padx=10, pady=10)
        lf_live.pack(fill=tk.X, pady=5)

        poll_ctrl_frame = tk.Frame(lf_live)
        poll_ctrl_frame.pack(fill=tk.X, pady=(0, 10))
        
        tk.Label(poll_ctrl_frame, text="Interval (ms):").pack(side=tk.LEFT)
        self.poll_interval_var = tk.StringVar(value="100")
        tk.Entry(poll_ctrl_frame, textvariable=self.poll_interval_var, width=5).pack(side=tk.LEFT, padx=5)
        self.btn_poll = tk.Button(poll_ctrl_frame, text="▶ Start Polling", command=self.toggle_polling, bg="#e0ffe0")
        self.btn_poll.pack(side=tk.LEFT, padx=5)

        # Create a grid of 12 indicator blocks
        self.btn_indicators = []
        ind_frame = tk.Frame(lf_live)
        ind_frame.pack(fill=tk.X)
        
        for i in range(12):
            lbl = tk.Label(ind_frame, text=f"B{i}", width=4, height=2, bg="#e0e0e0", relief=tk.RAISED)
            # Arrange in 3 rows of 4 columns
            lbl.grid(row=i//4, column=i%4, padx=3, pady=3)
            self.btn_indicators.append(lbl)

        # === TERMINAL SECTION ===
        tk.Label(terminal_frame, text="Serial Output Log:").pack(anchor="w")
        self.log_text = scrolledtext.ScrolledText(terminal_frame, wrap=tk.WORD, state='disabled')
        self.log_text.pack(fill=tk.BOTH, expand=True)

        # === FOOTER SECTION ===
        footer_frame = tk.Frame(self.root, padx=10, pady=10)
        footer_frame.pack(fill=tk.X, side=tk.BOTTOM)
        
        tk.Button(footer_frame, text="💾 Save Current Config to Flash", bg="#e0ffe0", height=2, command=lambda: self.send_cmd("S")).pack(side=tk.LEFT, expand=True, fill=tk.X, padx=(0, 5))
        tk.Button(footer_frame, text="⚠️ Reboot to DFU Bootloader", bg="#ffe0e0", height=2, command=lambda: self.send_cmd("Z")).pack(side=tk.RIGHT, expand=True, fill=tk.X, padx=(5, 0))

    # --- Hardware Command Generators ---
    def cmd_set_debounce(self):
        val = self.debounce_var.get()
        if val.isdigit(): self.send_cmd(f"t {val}")
        else: messagebox.showwarning("Input Error", "Debounce must be an integer.")

    def cmd_set_key(self):
        btn_idx = self.btn_sel_config.current()
        hex_val = HID_KEYS[self.key_cb.get()]
        self.send_cmd(f"k {btn_idx} {hex_val}")
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

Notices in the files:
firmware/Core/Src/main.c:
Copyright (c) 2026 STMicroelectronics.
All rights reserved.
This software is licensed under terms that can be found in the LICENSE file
